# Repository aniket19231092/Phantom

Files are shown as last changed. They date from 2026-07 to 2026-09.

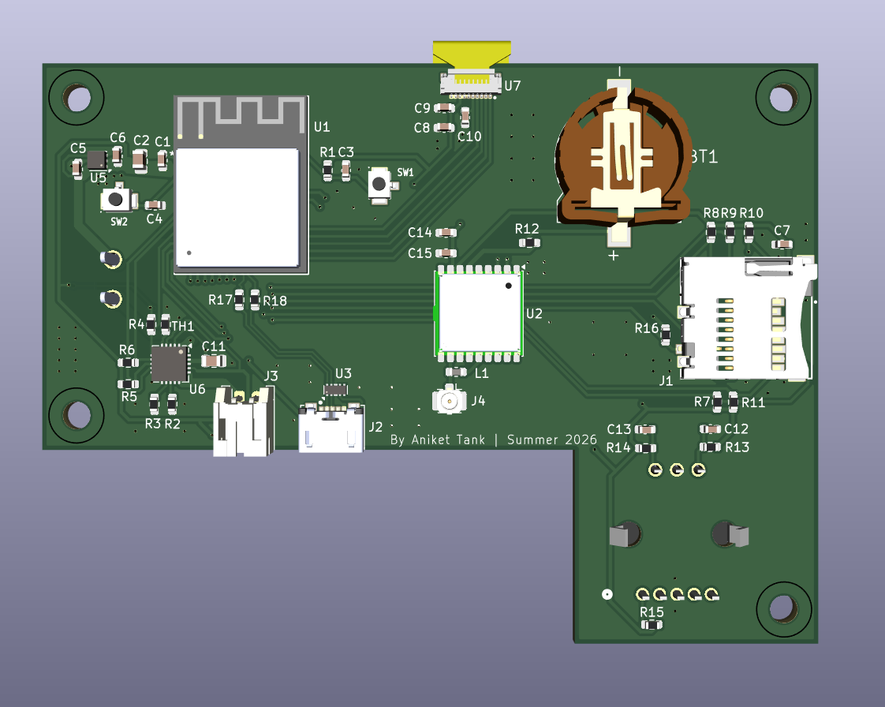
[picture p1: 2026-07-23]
Pictures/PCB Underside.png

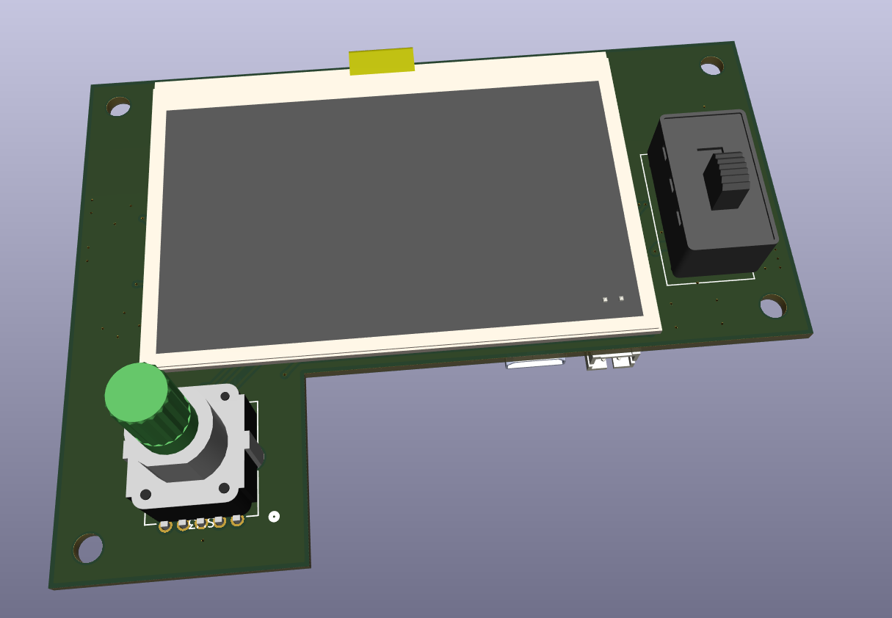
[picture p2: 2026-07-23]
Pictures/PCBTOP.png

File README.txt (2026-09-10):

Phantom ESP32
A lightweight open-source bicycle navigation computer built with the ESP32.

Phantom is a DIY GPS cycling computer designed for outdoor use. It combines an ESP32, u-blox MAX-M10M GPS receiver, Sharp Memory LCD, and microSD card to create a low-power navigation device capable of displaying maps, tracking rides, and providing real-time cycling metrics. Checkout the Pictures folder for pictures of the PCB and enclosure.

The Sharp Memory LCD provides excellent sunlight readability while consuming very little power, making it ideal for long rides.

This is a good project for those getting into embedded electronics and SMD soldering.
---
CAD
Only two parts are needed to be 3D printed, the top and bottom enclosure, which are found in the CAD folder. ABS is preferred because it needs to be able to
withstand the Sun. For assembly 4 M3 screws are needed, about 4-6mm in length is needed.

---
Features

- 🗺️ Offline map rendering from microSD card
- 📍 Real-time GPS positioning using the u-blox MAX-M10M
- 🚴 Live cycling data
  - Current speed
  - Average speed
  - Trip distance
  - Total distance
  - Heading
  - Ride time
- 🧭 Turn-by-turn capable map interface (planned)
- 💾 GPX ride logging to SD card
- 🌞 Sunlight-readable Sharp Memory LCD
- 🔋 Low power design for extended battery life
- 📡 Fast satellite acquisition with multi-band GNSS support
- Bluetooth capabilities for uploading to fitness apps such as Strava

---
Hardware

| Component | Description |
|---|---|
| ESP32 | Main processor |
| MAX-M10M GPS | High-performance GNSS receiver |
| Sharp Memory LCD | Outdoor-readable display |
| microSD Card Module | Offline maps and GPX storage |
| Li-Ion/LiPo Battery | Portable power |
| Battery Charger | USB charging circuit|
| Handlebar Mount | Bicycle mounting system |

Offline Maps

Maps are stored on the microSD card and loaded as needed.

Possible formats include:

- Raster map tiles
- Vector tiles (future)
- Custom compressed tile database

The map renderer centers on the current GPS position while displaying nearby roads and paths.

---

Ride Data

The computer continuously records:

- Current speed
- Average speed
- Maximum speed
- Total distance
- Ride duration
- GPS track
- Timestamp
- Latitude
- Longitude

Tracks are stored as GPX files for later upload to services such as Strava or Garmin Connect.

---

Why Sharp Memory LCD?

Unlike TFT or OLED displays, the Sharp Memory LCD offers:

- Excellent readability in direct sunlight
- Extremely low power consumption
- No backlight required during daytime
- Fast refresh for navigation
- Long battery life

These characteristics make it particularly well-suited for bicycle computers and outdoor GPS devices.

---

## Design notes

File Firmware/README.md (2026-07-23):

# Bike Computer Firmware

Starting firmware for the ESP32-S3-based bike computer: GPX route browsing,
map + route overlay display, ride recording (speed/avg speed/distance), and
rotary encoder navigation.

## Required libraries (Arduino Library Manager)

- **TinyGPSPlus** (Mikal Hart) - NMEA parsing
- **Adafruit GFX Library** - text/shape drawing primitives, used by the
  Sharp Memory LCD driver

## Board settings (Arduino IDE)

- Board: `ESP32S3 Dev Module` (or your custom board definition once made)
- USB Mode: **Hardware CDC and JTAG** (matches native USB D+/D- wiring)
- PSRAM: **Disabled** (this targets the `-N8` module variant, no PSRAM)
- Flash Size: 8MB

## SD card folder layout

```
/routes/
    morning_loop.gpx
    river_trail.gpx
    ...
/tiles/
    16/
        11241/
            26348.bin
            26349.bin
            ...
        11242/
            ...
    17/
        ...
```

## Map tile format (what your PC-side prep script must produce)

Each tile file is a **raw 1-bit-per-pixel monochrome bitmap**, no header:

- `TILE_SIZE x TILE_SIZE` pixels (currently 200x200, see `Config.h`)
- Row-major, MSB-first bit packing (bit 7 of byte 0 = pixel (0,0), etc.)
- File size must be exactly `(TILE_SIZE * TILE_SIZE) / 8` bytes = 5000 bytes
- 1 = white, 0 = black (matches the Sharp Memory LCD's native pixel format)
- Path: `/tiles/{zoom}/{tileX}/{tileY}.bin`
- Tile numbering follows the standard Web Mercator "slippy map" scheme
  (same as OpenStreetMap tile servers), just with a 200px tile size instead
  of the usual 256px. Standard formulas:

  ```
  n = 2^zoom
  tileX = floor((lon + 180) / 360 * n)
  tileY = floor((1 - ln(tan(lat_rad) + 1/cos(lat_rad)) / pi) / 2 * n)
  ```

  A PC-side script (not included here) would typically: pull source map
  tiles/vector data for your riding area, render each to a `TILE_SIZE x
  TILE_SIZE` monochrome image (e.g. via Pillow in Python, thresholding to
  1-bit), and write it out in this raw packed format at each zoom level you
  want to support (`MIN_ZOOM` to `MAX_ZOOM` in `Config.h`).

- Missing tiles (not on the card) render as blank/white rather than
  crashing - useful for partial map coverage of just your usual riding area.

## GPX parsing notes

The parser is a lightweight line-based scanner, not a full XML parser - it
looks for `<trkpt lat="..." lon="...">`, `<wpt lat="..." lon="...">`, and
`<name>` tags. This works with typical GPX 1.1 output (Strava, RideWithGPS,
GPX Studio, etc.) but has not been exhaustively tested against every GPX
variant - if a specific exported file fails to load, check whether its tags
span multiple lines in an unusual way.

Long routes are automatically decimated (every Nth point kept, coarsening
further if needed) to fit within `MAX_TRACK_POINTS` (1500) so very long GPX
files don't exhaust RAM - the overall route shape is preserved even if some
fine detail is thinned out.

## Encoder / button behavior implemented

- **Home screen**: file list from `/routes`, CW = move right/down, CCW =
  move left/up, press = load route and open map screen.
- **Map screen**: three-button bar (Back, Start/Stop, Zoom), same CW/CCW
  cycling, press = activate. Back is removed from the navigation cycle
  entirely while a ride is being recorded. Start/Stop toggles GPS ride
  recording (distance, avg speed, current speed). Zoom press enters a
  sub-mode where the encoder controls zoom level instead of button
  navigation; pressing again returns to normal navigation with the zoom
  level retained.
- Position arrow (heading-pointed) only appears once recording has started,
  per spec. GPS heading is frozen below ~1 m/s to avoid jitter when
  stopped/slow (see `GPS_STOPPED_THRESHOLD_MPS` in `Config.h`).

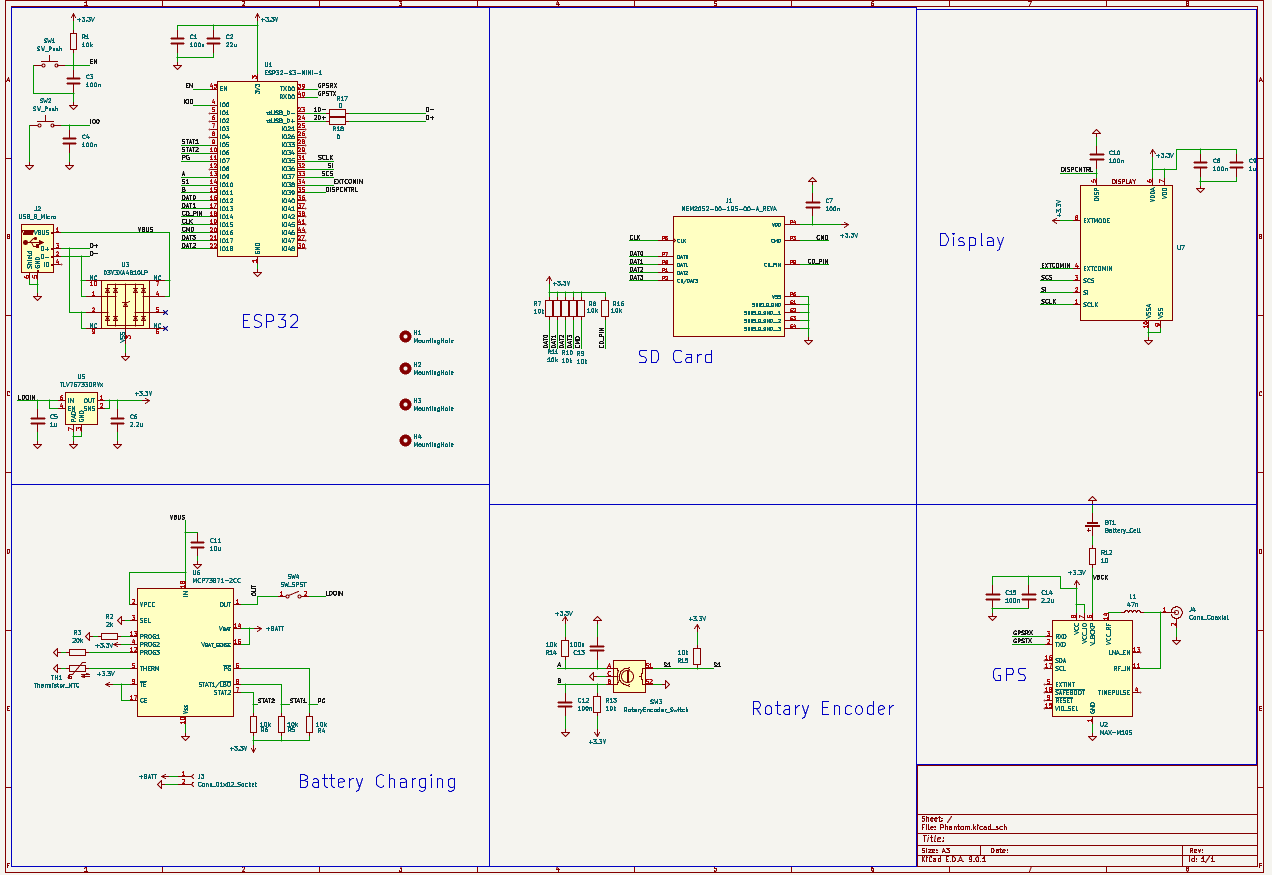
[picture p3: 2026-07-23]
Pictures/PCBSchematic.png

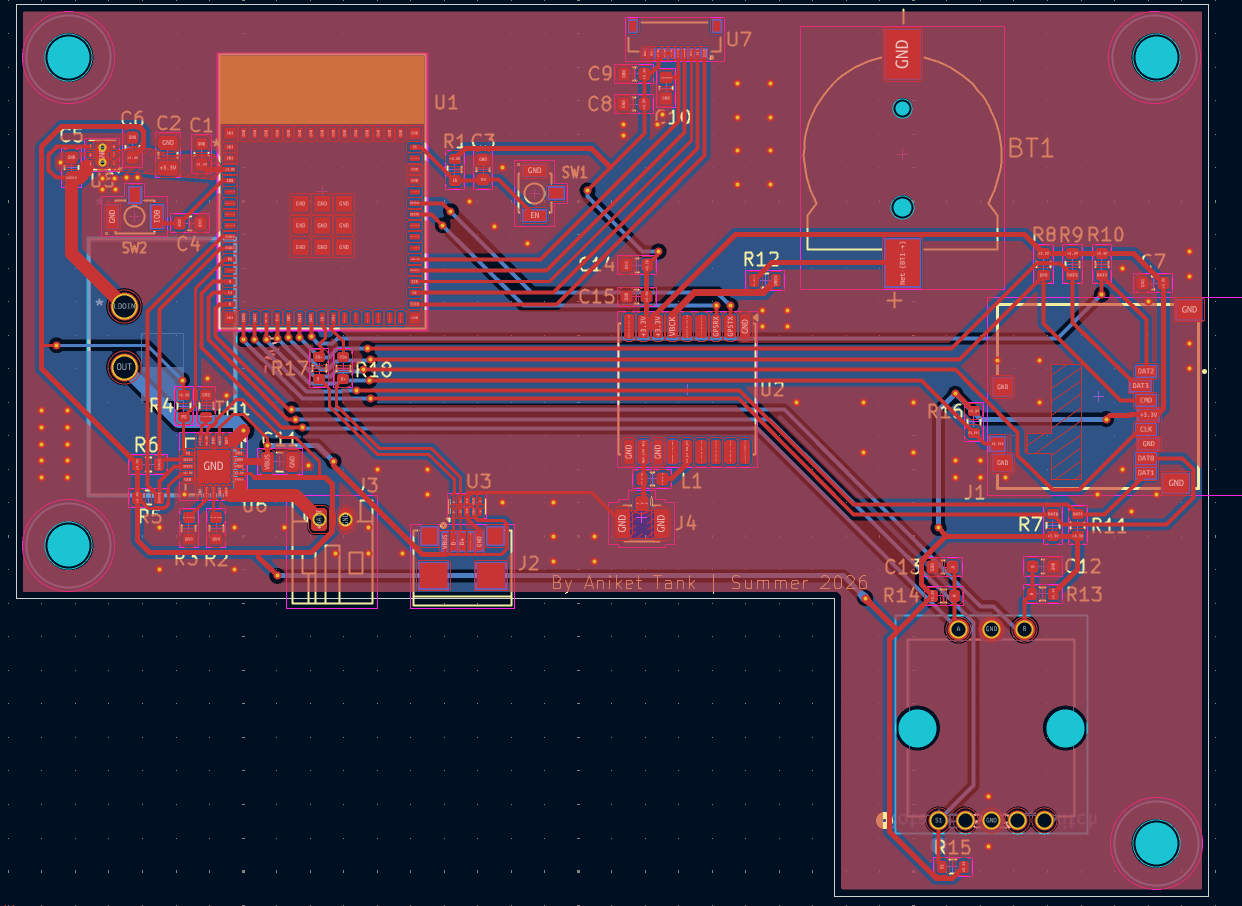
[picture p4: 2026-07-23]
Pictures/PCBDesign.png

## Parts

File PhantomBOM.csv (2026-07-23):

Item Name | Qty | Price (total) (USD) | Item link | Notes | PCB Designator
ESP32-S3-MINI1 | 1 | $5.43 | https://www.digikey.com/en/products/detail/espressif-systems/esp32-s3-mini-1-n8/15295890 | ESP32 Microcontroller and bluetooth | U1
MEM2052-00-195-00-A | 1 | $1.14 | https://www.digikey.com/en/products/detail/gct/MEM2052-00-195-00-A/18091687 | SD Card | J1
MAX-M10M-00B | 1 | $7.56 | https://www.digikey.com/en/products/detail/u-blox/MAX-M10M-00B/15712905 | GPS Chip | U2
DX4R005HJ5R2000 | 1 | $0.80 | https://www.digikey.com/en/products/detail/jae-electronics/DX4R005HJ5R2000/3903227 | USB | J2
LS027B7DH01A | 1 | $27.59 | https://www.digikey.com/en/products/detail/sharp-microelectronics/LS027B7DH01A/5054067 | Display | U7
B57330V2103J260 | 1 | $0.19 | https://www.digikey.com/en/products/detail/tdk/B57330V2103J260/4360622 | Thermistor | TH1
D3V3XA4B10LP-7 | 1 | $0.44 | https://www.digikey.com/en/products/detail/diodes-incorporated/D3V3XA4B10LP-7/10295141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 | EMI Protection | U3
TLV76733DRVR | 1 | $1.05 | https://www.digikey.com/en/products/detail/texas-instruments/TLV76733DRVR/10434657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 | Linear Voltage Regulator | U5
MCP73871-2CCI/ML | 1 | $2.41 | https://www.digikey.com/en/products/detail/microchip-technology/MCP73871-2CCI-ML/1680971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 | Battery Charging | U6
B3U-1100P | 2 | $1.17 | https://www.digikey.com/en/products/detail/omron-electronics-inc-emc-div/B3U-1100P/1534339?gclsrc=aw.ds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 | Push Button | SW1,SW2
PCB | 1 | $121.62 |  | Qoute from JLC PCB includes shipping/tarrifs
BC501SM | 1 | $1.37 | https://www.digikey.com/en/products/detail/mpd-memory-protection-devices/BC501SM/2439260 | Coin battery holder | BT1
15141 | 1 | $4.96 | https://www.digikey.com/en/products/detail/sparkfun-electronics/15141/10130910 | Rotary Encoder | SW3
L101011MS02Q | 1 | $3.97 | https://www.digikey.com/en/products/detail/c-k/L101011MS02Q/484142 | Power Switch | SW4
FH33-10S-0.5SH(10) | 1 | $1.22 | https://www.digikey.com/en/products/detail/hirose-electric-co-ltd/FH33-10S-0-5SH-10/1305324 | Screen Connector | U7
AGGP.25F.07.0060A | 1 | $19.30 | https://www.digikey.com/en/products/detail/taoglas-limited/aggp-25f-07-0060a/3083243 | GPS Antenna
U.FL-R-SMT-K(895) | 1 | $1.29 | https://www.digikey.com/en/products/detail/hirose-electric-co-ltd/U-FL-R-SMT-1-10/2391570 | GPS Antenna Connector | J4
B2B-PH-SM4-TB | 1 | $0.47 | https://www.digikey.com/en/models/926641?tab=snapmagic | Battery Connector | J3
C0603C104K5RACTU | 9 | $0.10 | https://www.digikey.com/en/products/detail/kemet/C0603C104K5RACTU/1465594 | 100nF Capacitor | C1,C3,C4,C7,C8,C10,C12,C13,C15
C1608X5R1H105K080AB | 2 | $0.16 | https://www.digikey.com/en/products/detail/tdk/C1608X5R1H105K080AB/2732903 | 1uF Capacitor | C5,C9
CL21A226KOQNNNE | 1 | $0.35 | https://www.digikey.com/en/products/detail/samsung-electro-mechanics/CL21A226KOQNNNE/5961010 | 22uF Capacitor | C2
CL21A225KOFNNNE | 2 | $0.13 | https://www.digikey.com/en/products/detail/samsung-electro-mechanics/CL21A225KOFNNNE/3887439 | 2.2uF Capacitor | C6,C14
CL21A106KOFNNNE | 1 | $0.16 | https://www.digikey.com/en/products/detail/samsung-electro-mechanics/CL21A106KOFNNNE/3888551 | 10uF Capcitor | C11
CR0603-FX-1002ELF | 13 | $0.10 | https://www.digikey.com/en/products/detail/bourns-inc/CR0603-FX-1002ELF/3593188 | 10k Ohm Resistor | R1,R4,R5,R6,R7,R8,R9,R10,11,R13,R14,R15,R16
CR2512-FX-2001ELF | 1 | $0.23 | https://www.digikey.com/en/products/detail/bourns-inc/CR2512-FX-2001ELF/4698121 | 2k Ohm Resistor | R2
RN73H1JTTD2032D25 | 1 | $0.10 | https://www.digikey.com/en/products/detail/koa-speer-electronics-inc/RN73H1JTTD2032D25/10682841 | 20k Ohm Resistor | R3
CRGH0603F10R | 1 | $0.12 | https://www.digikey.com/en/products/detail/te-connectivity-passive-product/CRGH0603F10R/2386211 | 10 Ohm Resistor | R12
MCT06030Z0000ZP500 | 2 | $0.19 | https://www.digikey.com/en/products/detail/vishay/MCT06030Z0000ZP500/2607867 | 0 Ohm Resistor | R17,R18
Total Price (USD): | 207.27

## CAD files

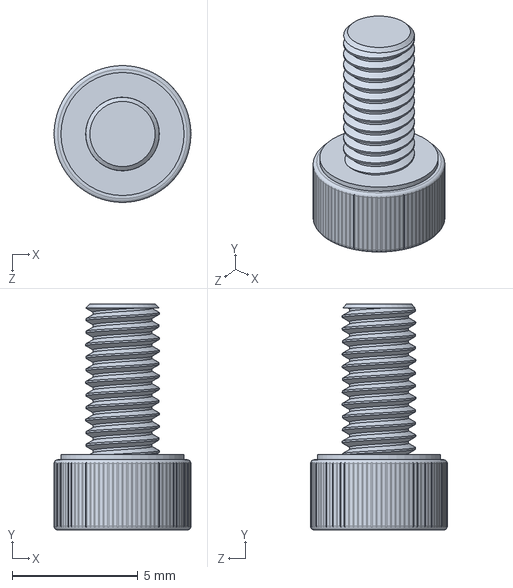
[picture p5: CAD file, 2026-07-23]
CAD/Solidworks Parts/CHC M3 L6.SLDPRT
5.45 x 9.00 x 5.45 mm

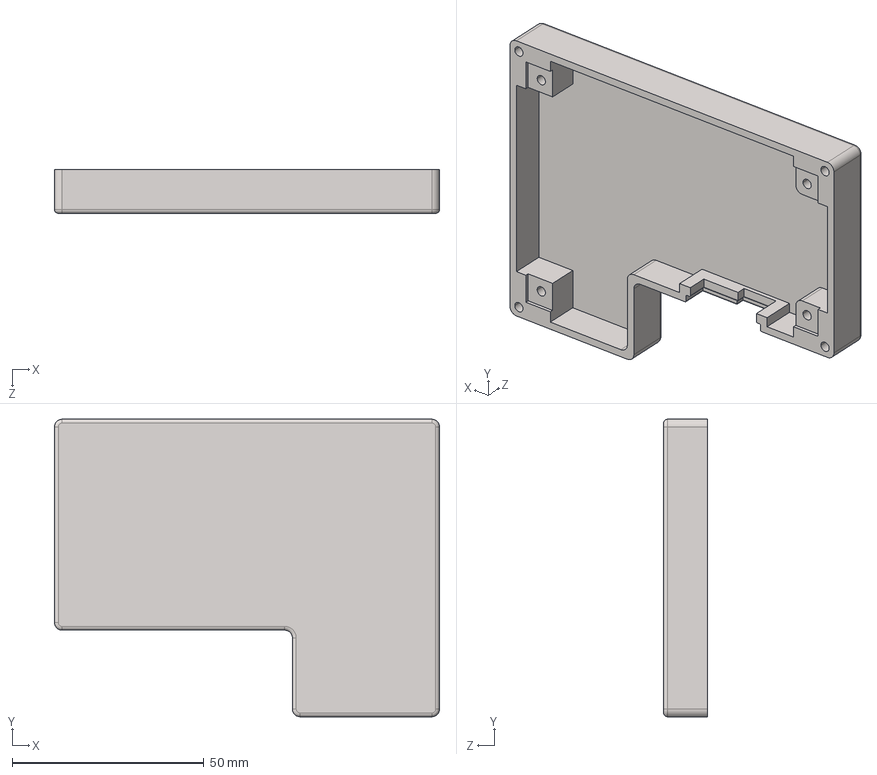
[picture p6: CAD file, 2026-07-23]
CAD/BottomEnclosure.STEP
100.4 x 77.6 x 11.4 mm

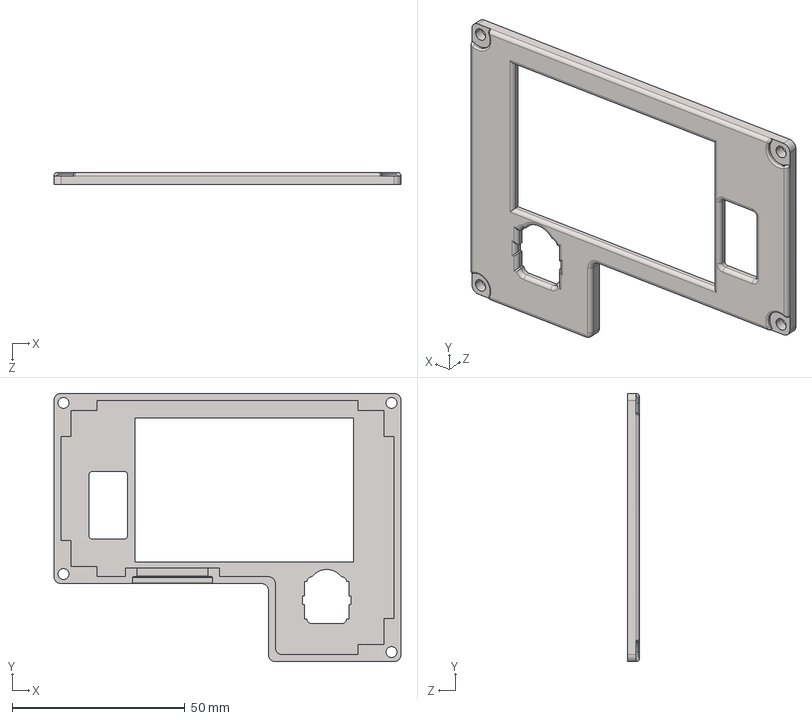
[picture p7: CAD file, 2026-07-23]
CAD/TopEnclosure.STEP
100.4 x 77.6 x 3.50 mm

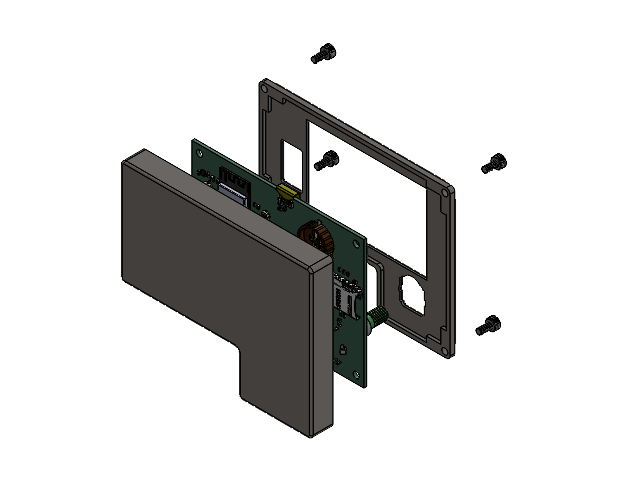
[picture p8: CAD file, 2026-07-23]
CAD/PhantomAssemblySplit.SLDASM
PhantomPCB
BottomEnclosure
TopEnclosure
CHC M3 L6 x 4

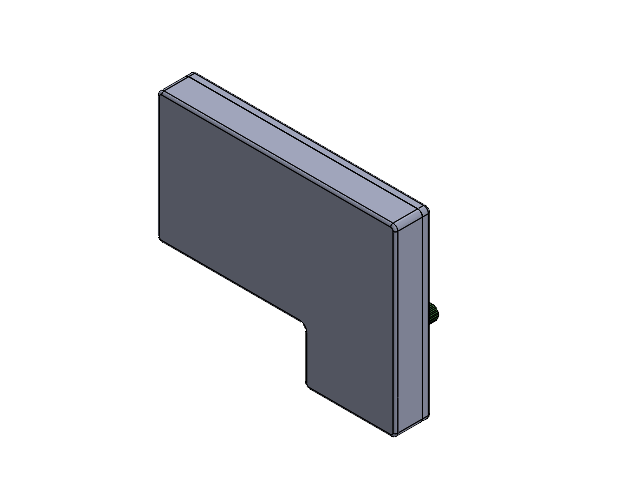
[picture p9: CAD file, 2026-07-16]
CAD/Solidworks Parts/PhantomAssembly.SLDASM
PhantomPCB
Part4^PhantomAssembly

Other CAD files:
CAD/Solidworks Parts/BottomEnclosure.SLDPRT
CAD/Solidworks Parts/TopEnclosure.SLDPRT

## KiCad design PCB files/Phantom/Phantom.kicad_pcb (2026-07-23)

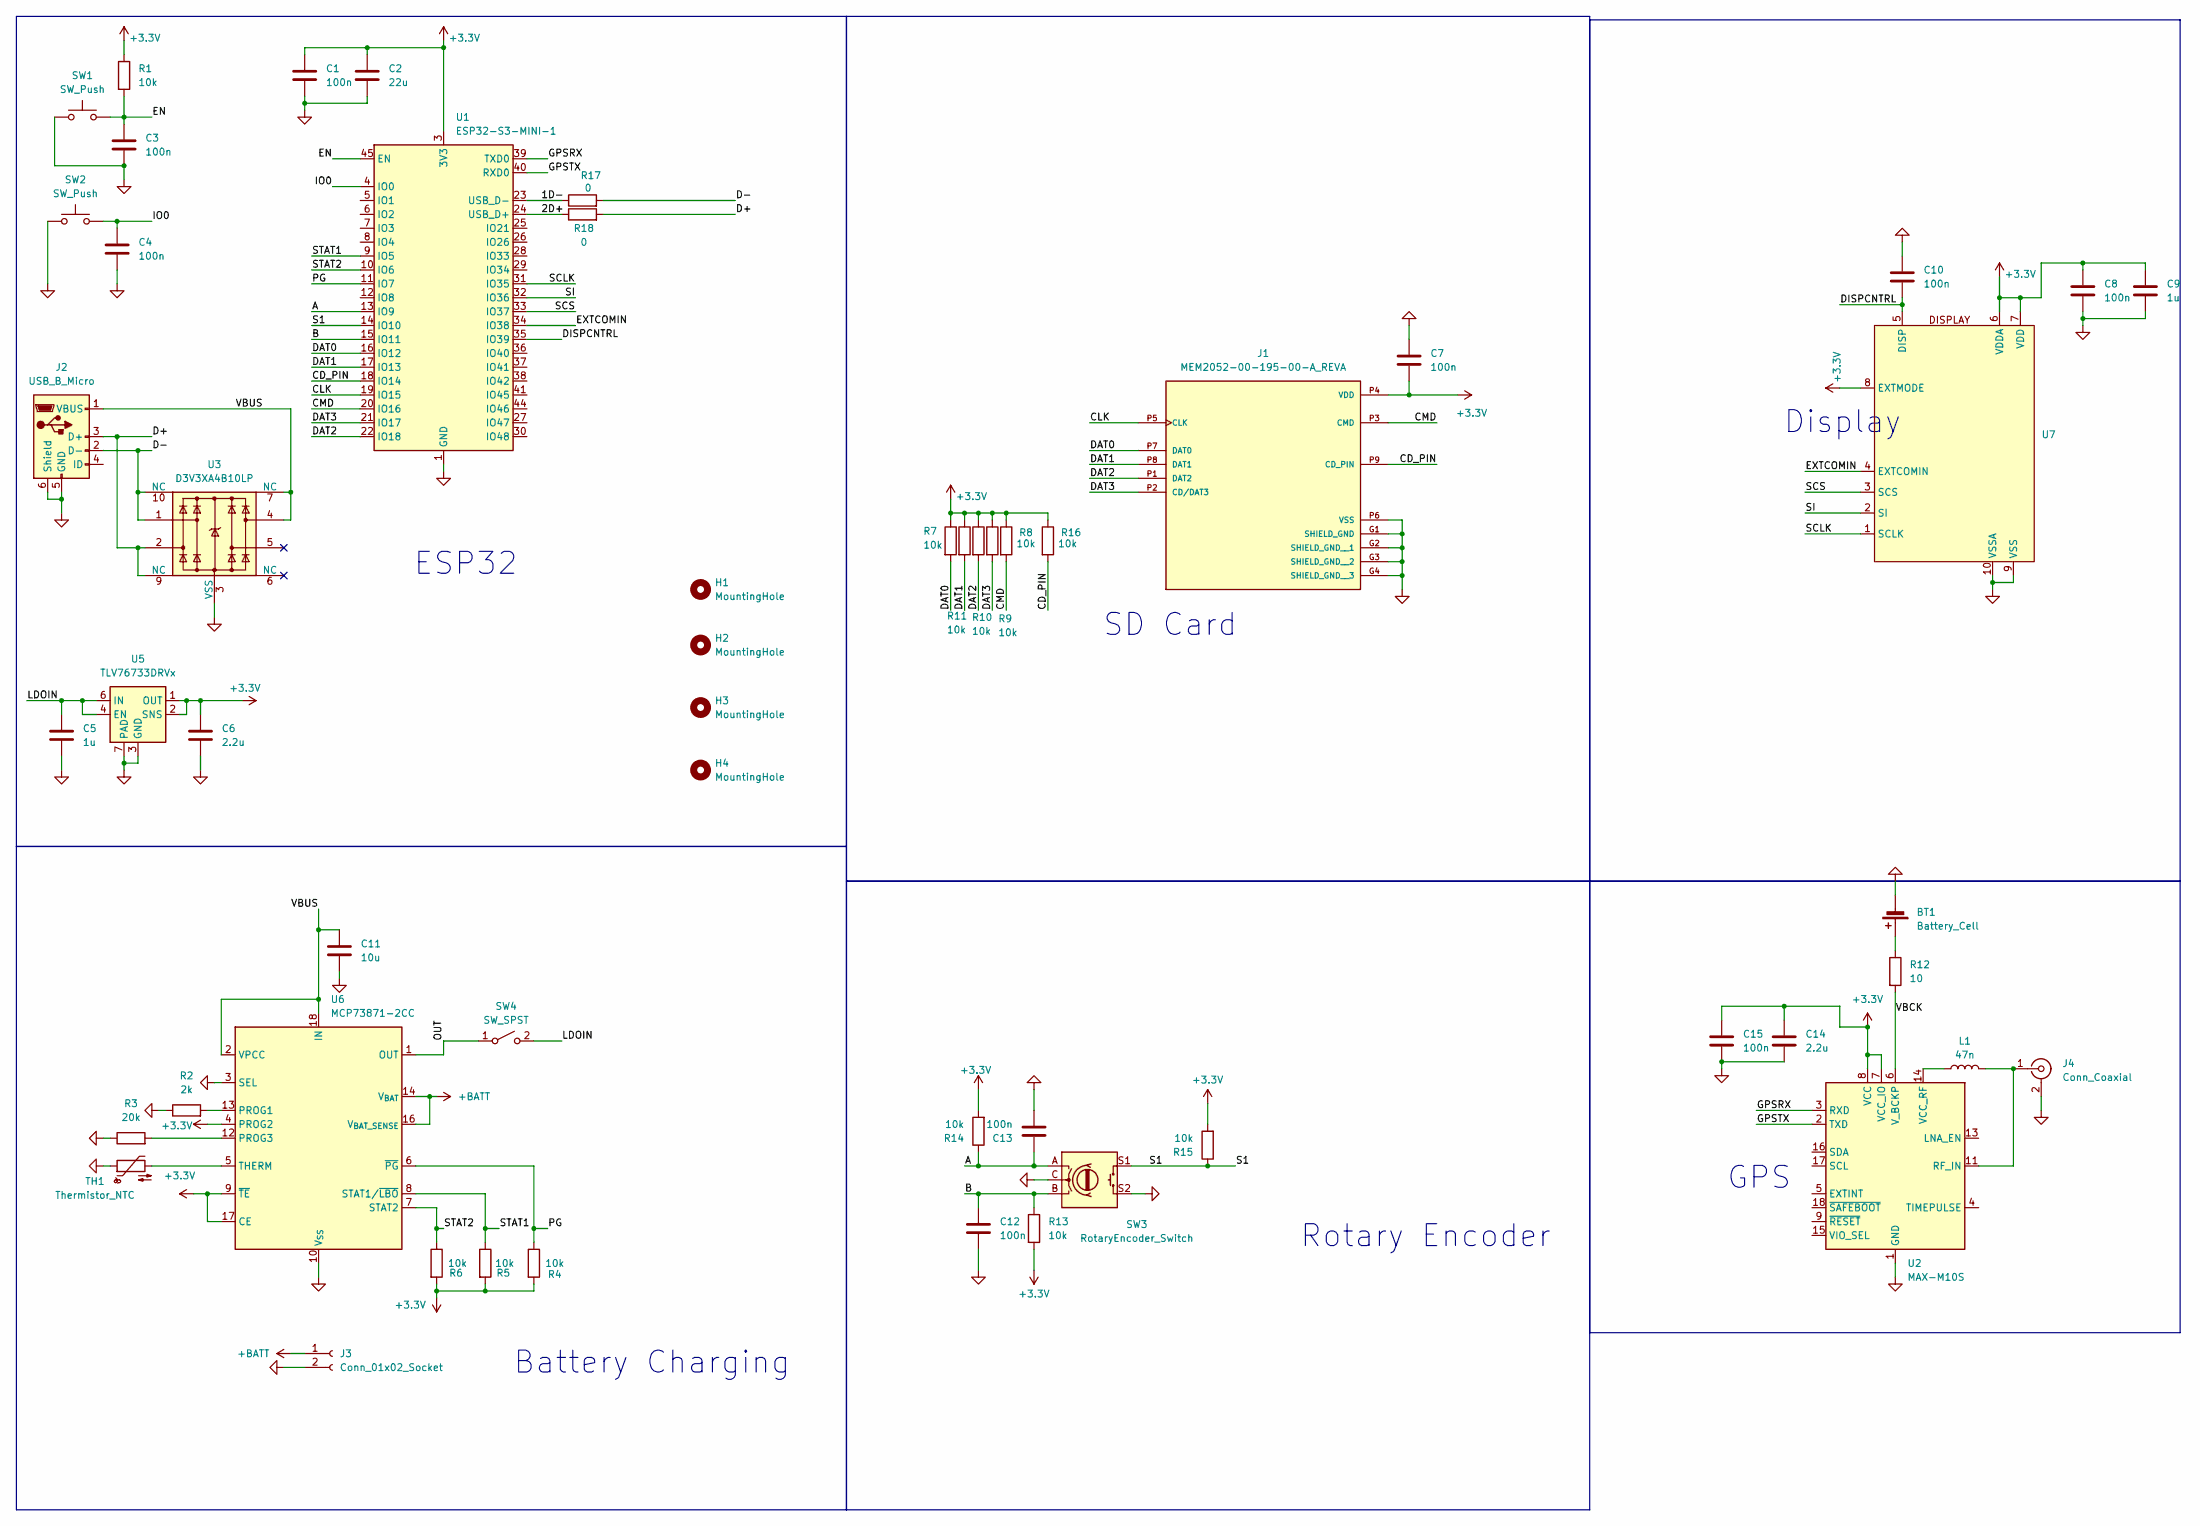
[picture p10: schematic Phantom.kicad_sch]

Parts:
BT1: Battery_Cell; BAT_BC501SM
C1, C3, C4, C7, C8, C10, C12, C13, C15: 100n; C_0603_1608Metric
C2: 22u; C_0805_2012Metric
C5, C9: 1u; C_0603_1608Metric
C6, C14: 2.2u; C_0603_1608Metric
C11: 10u; C_0805_2012Metric
H1, H2, H3, H4: MountingHole; MountingHole_3.2mm_M3
J1: MEM2052-00-195-00-A_REVA; GCT_MEM2052-00-195-00-A_REVA; PARTREV A
J2: USB_B_Micro; JAE_DX4R005HJ5R2000
J3: Conn_01x02_Socket; JST_PH_S2B-PH-K_1x02_P2.00mm_Horizontal
J4: Conn_Coaxial; U.FL_Hirose_U.FL-R-SMT-1_Vertical
L1: 47n; L_0603_1608Metric
R1, R4, R5, R6, R7, R8, R9, R10, R11, R13, R14, R15, R16: 10k; R_0603_1608Metric
R2: 2k; R_0603_1608Metric
R3: 20k; R_0603_1608Metric
R12: 10; R_0603_1608Metric
R17, R18: 0; R_0603_1608Metric
SW1, SW2: SW_Push; SW_B3U-1100P
SW3: RotaryEncoder_Switch; COM-15141_SPK
SW4: SW_SPST; SW_1MS02Q_CNK
TH1: Thermistor_NTC; R_0603_1608Metric
U1: ESP32-S3-MINI-1; ESP32-S3-MINI-1_EXP
U2: MAX-M10S; ublox_MAX
U3: D3V3XA4B10LP; Diodes_UDFN-10_1.0x2.5mm_P0.5mm
U5: TLV76733DRVx; WSON-6-1EP_2x2mm_P0.65mm_EP1x1.6mm_ThermalVias
U6: MCP73871-2CC; QFN-20-1EP_4x4mm_P0.5mm_EP2.5x2.5mm
U7: HRS_FH33-10S-0.5SH_10_

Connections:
+3.3V: C1.1, C2.1, C6.1, C7.1, C8.1, C9.1, C14.2, C15.2, J1.P4 (VDD), R1.1, R4.2, R5.2, R6.2, R7.1, R8.1, R9.1, R10.1, R11.1, R13.2, R14.2, R15.2, R16.1, U1.3 (3V3), U2.7 (VCC_IO), U2.8 (VCC), U5.1 (OUT), U5.2 (SNS), U6.4 (PROG2), U6.9 (~TE), U6.17 (CE), U7.6 (VDDA), U7.7 (VDD), U7.8 (EXTMODE)
+BATT: J3.1, U6.14 (V_{BAT}), U6.15 (V_{BAT}), U6.16 (V_{BAT_SENSE})
/1D-: R17.1, U1.23 (USB_D-)
/2D+: R18.1, U1.24 (USB_D+)
/A: C13.1, R14.1, SW3.A, U1.13 (IO9)
/B: C12.1, R13.1, SW3.B, U1.15 (IO11)
/CD_PIN: J1.P9 (CD_PIN), R16.2, U1.18 (IO14)
/CLK: J1.P5 (CLK), U1.19 (IO15)
/CMD: J1.P3 (CMD), R8.2, U1.20 (IO16)
/D+: J2.3 (D+), R18.2, U3.2, U3.9 (NC)
/D-: J2.2 (D-), R17.2, U3.1, U3.10 (NC)
/DAT0: J1.P7 (DAT0), R7.2, U1.16 (IO12)
/DAT1: J1.P8 (DAT1), R11.2, U1.17 (IO13)
/DAT2: J1.P1 (DAT2), R10.2, U1.22 (IO18)
/DAT3: J1.P2 (CD/DAT3), R9.2, U1.21 (IO17)
/DISPCNTRL: C10.1, U1.35 (IO39), U7.5 (DISP)
/EN: C3.1, R1.2, SW1.2, U1.45 (EN)
/EXTCOMIN: U1.34 (IO38), U7.4 (EXTCOMIN)
/GPSRX: U1.39 (TXD0), U2.3 (RXD)
/GPSTX: U1.40 (RXD0), U2.2 (TXD)
/IO0: C4.1, SW2.2, U1.4 (IO0)
/LDOIN: C5.1, SW4.2 (B), U5.4 (EN), U5.6 (IN)
/OUT: SW4.1 (A), U6.1 (OUT), U6.20 (OUT)
/PG: R4.1, U1.11 (IO7), U6.6 (~PG)
/S1: R15.1, SW3.S1, U1.14 (IO10)
/SCLK: U1.31 (IO35), U7.1 (SCLK)
/SCS: U1.33 (IO37), U7.3 (SCS)
/SI: U1.32 (IO36), U7.2 (SI)
/STAT1: R5.1, U1.9 (IO5), U6.8 (STAT1/~LBO)
/STAT2: R6.1, U1.10 (IO6), U6.7 (STAT2)
/VBCK: R12.2, U2.6 (V_BCKP)
/VBUS: C11.1, J2.1 (VBUS), U3.4, U3.7 (NC), U6.2 (VPCC), U6.18 (IN), U6.19 (IN)
GND: BT1.2 (-), C1.2, C2.2, C3.2, C4.2, C5.2, C6.2, C7.2, C8.2, C9.2, C10.2, C11.2, C12.2, C13.2, C14.1, C15.1, J1.G1 (SHIELD_GND), J1.G2 (SHIELD_GND__1), J1.G3 (SHIELD_GND__2), J1.G4 (SHIELD_GND__3), J1.P6 (VSS), J2.5 (GND), J2.6 (Shield), J3.2, J4.2 (Ext), R2.1, R3.1, SW1.1, SW2.1, SW3.C, SW3.S2, TH1.1, U1.1 (GND), U1.2 (GND), U1.42 (GND), U1.43 (GND), U1.46 (GND), U1.47 (GND), U1.48 (GND), U1.49 (GND), U1.50 (GND), U1.51 (GND), U1.52 (GND), U1.53 (GND), U1.54 (GND), U1.55 (GND), U1.56 (GND), U1.57 (GND), U1.58 (GND), U1.59 (GND), U1.60 (GND), U1.61 (GND), U1.62 (GND), U1.63 (GND), U1.64 (GND), U1.65 (GND), U2.1 (GND), U2.10 (GND), U2.12 (GND), U3.3 (VSS), U3.8 (VSS), U5.3 (GND), U5.5 (GND), U5.7 (PAD), U6.3 (SEL), U6.10 (V_{SS}), U6.11 (V_{SS}), U6.21 (V_{SS}), U7.9 (VSS), U7.10 (VSSA)
unnamed: BT1.1 (+), R12.1
unnamed: J4.1 (In), L1.2, U2.11 (RF_IN)
unnamed: L1.1, U2.14 (VCC_RF)
unnamed: R2.2, U6.13 (PROG1)
unnamed: R3.2, U6.12 (PROG3)
unnamed: TH1.2, U6.5 (THERM)

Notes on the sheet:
Battery Charging
Rotary Encoder
ESP32
GPS
Display
SD Card

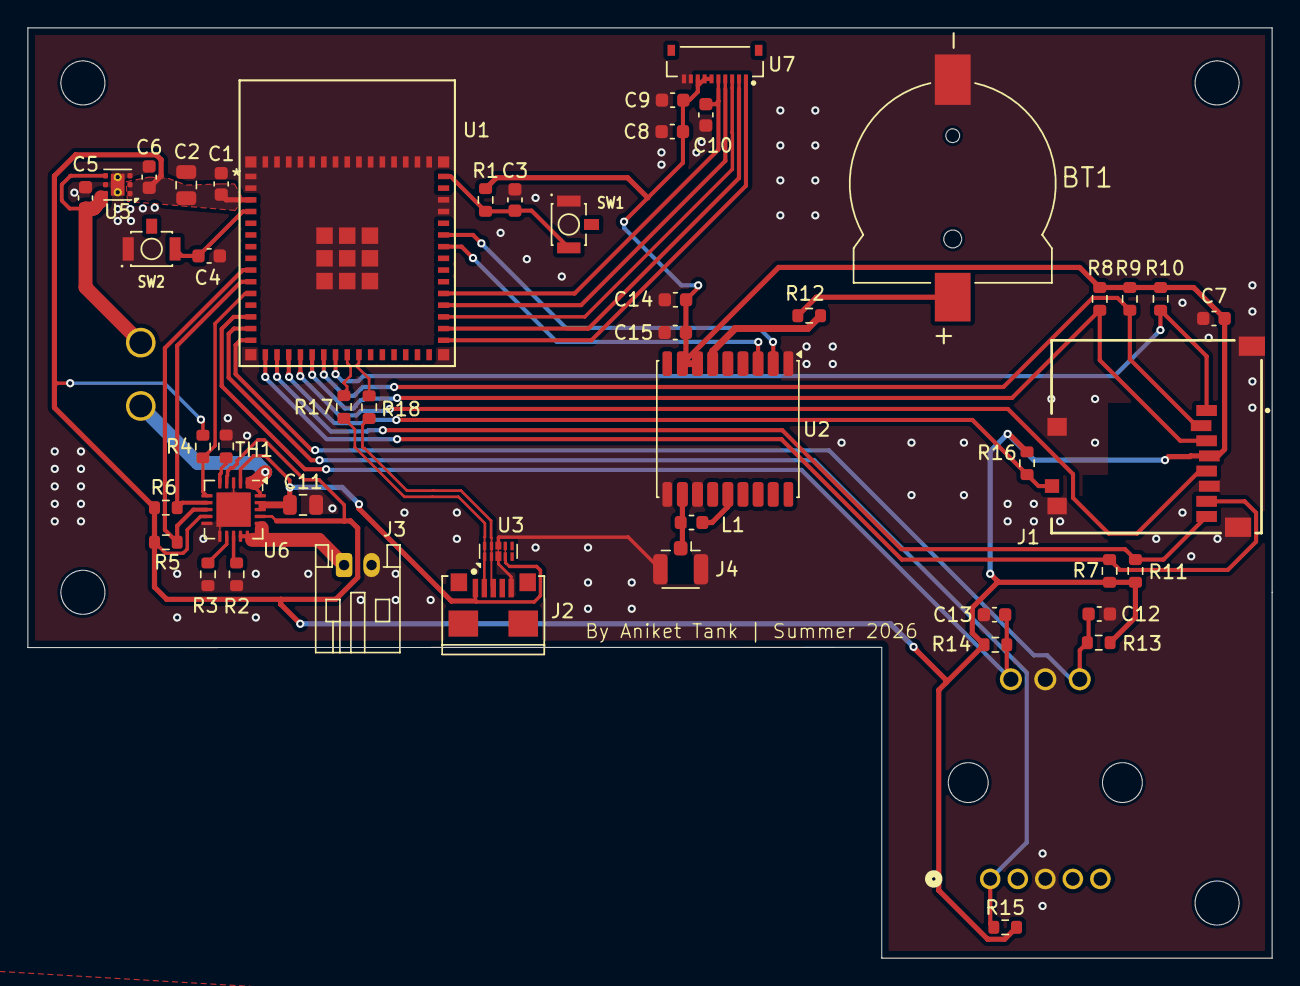
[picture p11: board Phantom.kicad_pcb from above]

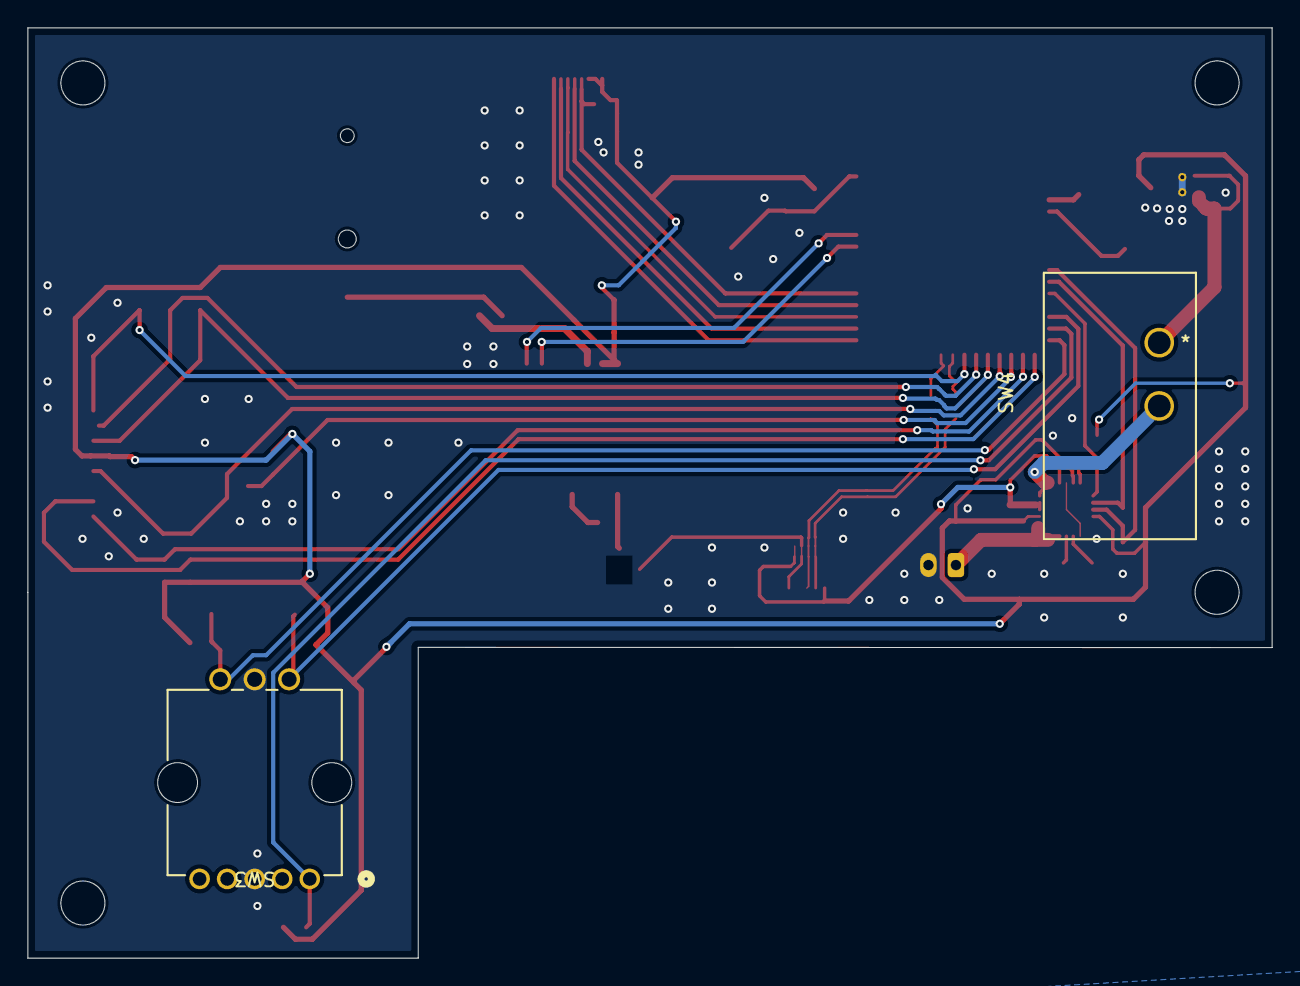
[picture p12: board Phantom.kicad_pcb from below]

Board: 2 copper layers, 90.4 x 67.6 mm, 54 parts (2 on the bottom side), 39 nets.

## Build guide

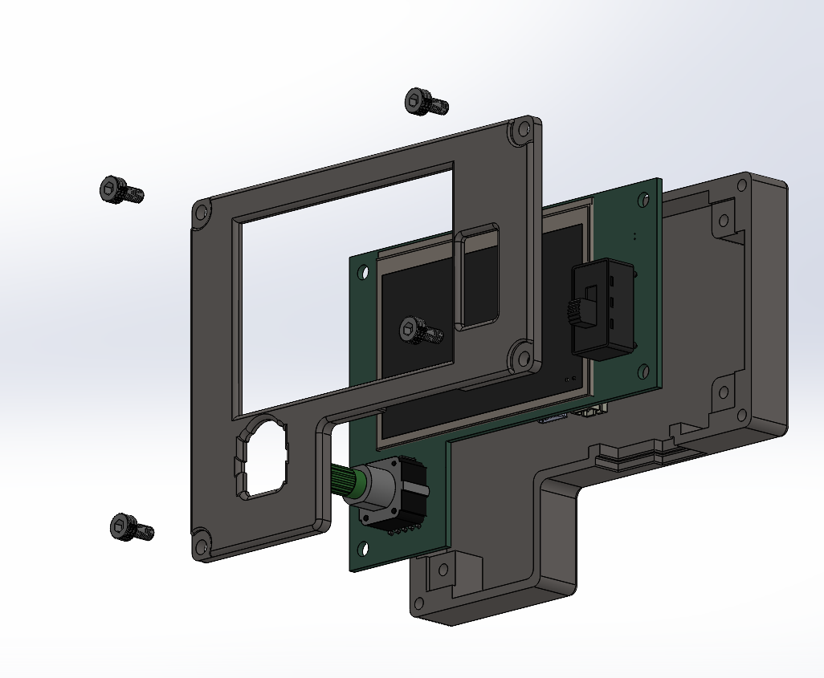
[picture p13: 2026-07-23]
Pictures/Assemblypic.png

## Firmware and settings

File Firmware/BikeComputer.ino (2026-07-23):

/*
 * BikeComputer.ino
 *
 * Top-level sketch. All actual logic lives in the other tabs in this
 * sketch folder (Arduino IDE shows them as tabs automatically) -
 * this file just wires the modules together.
 *
 * Required libraries (install via Library Manager):
 *   - TinyGPSPlus (Mikal Hart)
 *   - Adafruit GFX Library
 *
 * Board: ESP32S3 Dev Module (or your custom board definition), with:
 *   - USB Mode: Hardware CDC and JTAG (native USB, matches D+/D- on the
 *     board's fixed USB pins)
 *   - PSRAM: Disabled (this build targets the -N8 module, no PSRAM)
 *   - Partition scheme: Default (or Minimal SPIFFS if flash is tight)
 *
 * See README.md for the SD card folder layout and map tile format spec.
 */

#include "Config.h"
#include "SharpMemLCD.h"
#include "RotaryEncoder.h"
#include "GPSModule.h"
#include "SDStorage.h"
#include "BatteryMonitor.h"
#include "UIScreens.h"

SharpMemLCD display;
RotaryEncoder encoder;
GPSModule gps;
SDStorage storage;
BatteryMonitor battery;
UIScreens ui;

void setup() {
  Serial.begin(115200);

  display.begin();
  encoder.begin();
  gps.begin();
  battery.begin();

  if (!storage.begin()) {
    // SD card failed to mount - show a message and halt UI init, but keep
    // looping so the user can power-cycle after inserting/checking the card
    // rather than the device appearing fully dead.
    display.setTextColor(0);
    display.setTextSize(1);
    display.setCursor(10, 10);
    display.print("SD card not found.");
    display.setCursor(10, 25);
    display.print("Insert card and restart.");
    display.refresh();
    while (true) {
      delay(1000);
    }
  }

  ui.begin(&display, &encoder, &gps, &storage, &battery);
}

void loop() {
  gps.update();
  ui.update();
}

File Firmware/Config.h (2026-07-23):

#pragma once
/*
 * Config.h
 * Central pin map and constants for the bike computer.
 * Pin numbers match the finalized schematic GPIO assignment pass.
 */

#include <Arduino.h>

// ---------------------------------------------------------------------------
// SD Card (SDMMC 4-bit mode)
// ---------------------------------------------------------------------------
#define PIN_SD_CLK      15
#define PIN_SD_CMD      16
#define PIN_SD_DAT0     12
#define PIN_SD_DAT1     13
#define PIN_SD_DAT2     18
#define PIN_SD_DAT3     17
#define PIN_SD_CD       14   // Card detect switch (active LOW when card present, external pull-up)

// ---------------------------------------------------------------------------
// Sharp Memory LCD (LS027B7DH01A) - software/hardware SPI + control pins
// ---------------------------------------------------------------------------
#define PIN_LCD_SCLK      35
#define PIN_LCD_SI        36
#define PIN_LCD_SCS       37
#define PIN_LCD_EXTCOMIN  38   // Hardware-toggled via LEDC (EXTMODE tied HIGH in hardware)
#define PIN_LCD_DISP      39   // DISP control - drive HIGH to turn panel on

#define LCD_WIDTH   400
#define LCD_HEIGHT  240

// EXTCOMIN toggle frequency (Hz) - typical Sharp Memory LCD spec is ~1Hz min,
// using 2Hz here for margin. Driven entirely in hardware via LEDC, no CPU time.
#define LCD_EXTCOMIN_FREQ_HZ  2

// ---------------------------------------------------------------------------
// Rotary encoder + push button
// ---------------------------------------------------------------------------
#define PIN_ENC_A       9
#define PIN_ENC_B       11
#define PIN_ENC_BTN     10   // Active LOW (external pull-up), debounced in firmware

// ---------------------------------------------------------------------------
// GPS (MAX-M10S) - UART
// ---------------------------------------------------------------------------
#define PIN_GPS_TX      43   // ESP32 TX -> GPS RXD
#define PIN_GPS_RX      44   // ESP32 RX <- GPS TXD
#define GPS_BAUD        9600
#define GPS_UART_NUM    1

// ---------------------------------------------------------------------------
// Battery charger status (MCP73871) - open-drain, external pull-ups
// ---------------------------------------------------------------------------
#define PIN_CHG_STAT1   5   // Charging / low-battery indicator
#define PIN_CHG_STAT2   7   // Charge-complete indicator
#define PIN_CHG_PG      6   // Power-good (input power present)

// ---------------------------------------------------------------------------
// Filesystem layout on SD card
// ---------------------------------------------------------------------------
#define ROUTES_DIR      "/routes"     // .gpx files live here
#define TILES_DIR       "/tiles"      // /tiles/{zoom}/{x}/{y}.bin

// Tile format (produced by a PC-side prep script, see README):
//   - Raw 1-bit-per-pixel monochrome bitmap, row-major, MSB first
//   - TILE_SIZE x TILE_SIZE pixels, no header
//   - File size must be exactly (TILE_SIZE * TILE_SIZE) / 8 bytes
#define TILE_SIZE       200
#define TILE_BYTES      ((TILE_SIZE * TILE_SIZE) / 8)

#define MIN_ZOOM        12
#define MAX_ZOOM        18
#define DEFAULT_ZOOM    16

// ---------------------------------------------------------------------------
// Ride-recording behavior
// ---------------------------------------------------------------------------
#define GPS_STOPPED_THRESHOLD_MPS   1.0f   // below this, freeze heading/speed jitter
#define GPS_FIX_TIMEOUT_MS          3000

// ---------------------------------------------------------------------------
// Encoder debounce / PCNT config
// ---------------------------------------------------------------------------
#define ENC_BTN_DEBOUNCE_MS   40
#define PCNT_UNIT_ENCODER      0   // pcnt_unit_t value used for the rotary encoder

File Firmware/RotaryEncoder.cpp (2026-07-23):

#include "RotaryEncoder.h"

void RotaryEncoder::begin() {
  // --- Button ---
  pinMode(PIN_ENC_BTN, INPUT); // external pull-up already on the board
  _btnLastState = _btnStableState = digitalRead(PIN_ENC_BTN);

  // --- Quadrature decode via PCNT ---
  pcnt_config_t cfgA = {};
  cfgA.pulse_gpio_num = PIN_ENC_A;
  cfgA.ctrl_gpio_num   = PIN_ENC_B;
  cfgA.channel         = PCNT_CHANNEL_0;
  cfgA.unit            = (pcnt_unit_t)PCNT_UNIT_ENCODER;
  cfgA.pos_mode        = PCNT_COUNT_DEC;   // rising edge on A
  cfgA.neg_mode        = PCNT_COUNT_INC;   // falling edge on A
  cfgA.lctrl_mode      = PCNT_MODE_KEEP;
  cfgA.hctrl_mode      = PCNT_MODE_REVERSE;
  cfgA.counter_h_lim   = 32000;
  cfgA.counter_l_lim   = -32000;
  pcnt_unit_config(&cfgA);

  pcnt_config_t cfgB = {};
  cfgB.pulse_gpio_num = PIN_ENC_B;
  cfgB.ctrl_gpio_num   = PIN_ENC_A;
  cfgB.channel         = PCNT_CHANNEL_1;
  cfgB.unit            = (pcnt_unit_t)PCNT_UNIT_ENCODER;
  cfgB.pos_mode        = PCNT_COUNT_INC;
  cfgB.neg_mode        = PCNT_COUNT_DEC;
  cfgB.lctrl_mode      = PCNT_MODE_REVERSE;
  cfgB.hctrl_mode      = PCNT_MODE_KEEP;
  cfgB.counter_h_lim   = 32000;
  cfgB.counter_l_lim   = -32000;
  pcnt_unit_config(&cfgB);

  // Hardware glitch filter - rejects pulses shorter than ~1us (contact bounce)
  pcnt_set_filter_value((pcnt_unit_t)PCNT_UNIT_ENCODER, 100);
  pcnt_filter_enable((pcnt_unit_t)PCNT_UNIT_ENCODER);

  pcnt_counter_pause((pcnt_unit_t)PCNT_UNIT_ENCODER);
  pcnt_counter_clear((pcnt_unit_t)PCNT_UNIT_ENCODER);
  pcnt_counter_resume((pcnt_unit_t)PCNT_UNIT_ENCODER);

  _lastCount = 0;
}

int16_t RotaryEncoder::readSteps() {
  int16_t raw = 0;
  pcnt_get_counter_value((pcnt_unit_t)PCNT_UNIT_ENCODER, &raw);

  // This encoder is 24 pulses/rev (1 detent per full quadrature cycle).
  // With X4 decoding that's 4 counts per detent - divide down accordingly.
  int16_t delta = (raw - _lastCount);
  int16_t detents = delta / 4;

  if (detents != 0) {
    _lastCount += detents * 4;
  }
  return detents; // positive = CW/right, negative = CCW/left
}

bool RotaryEncoder::buttonPressed() {
  bool reading = digitalRead(PIN_ENC_BTN);
  uint32_t now = millis();

  if (reading != _btnLastState) {
    _btnLastChangeMs = now;
    _btnLastState = reading;
  }

  if ((now - _btnLastChangeMs) > ENC_BTN_DEBOUNCE_MS) {
    if (reading != _btnStableState) {
      _btnStableState = reading;
      if (_btnStableState == LOW) { // active LOW = pressed
        _btnEventPending = true;
      }
    }
  }

  if (_btnEventPending) {
    _btnEventPending = false;
    return true;
  }
  return false;
}

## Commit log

2026-07-01 Started work on the Schematic
    [Phantom.kicad_pcb, Phantom.kicad_sch, PhantomBOM.xlsx]
2026-07-02 Schematic work
    [Phantom.kicad_pcb, Phantom.kicad_sch, PhantomBOM.xlsx]
2026-07-12 Finished PCB and starting CAD
    [Phantom.kicad_pcb, Phantom.kicad_sch, PhantomAssembly.SLDASM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]
2026-07-23 PCB Fix
    [CHC M3 L6.SLDPRT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]
2026-07-23 Update README with beginner project note
    Added a note about the project being suitable for beginners in embedded electronics and SMD soldering.
2026-07-23 Update README with CAD and project information
    Added CAD section and updated project details.
2026-07-23 Revise README with project details and images reference
    Updated README to include additional details about the project, including a reference to the Pictures folder for PCB and enclosure images.
